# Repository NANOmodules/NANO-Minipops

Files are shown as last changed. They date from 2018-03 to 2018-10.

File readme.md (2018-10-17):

# NANO - Minipops

Arduino project based in Minipops design by Jan Ostman (DSP Synthesizers) 

The hardware consists in an Arduino Uno including it shield with 9 slide switches, 2 rotary potentiometers and 1 LED. 
Software in the CODE folder contains all the necessary to convert your Arduino Uno in a Minipops drum box.

**Click on the image to watch the presentation video!**

NANO-Minipops (https://www.youtube.com/watch?v=v7ahzl_3tDo&t=2s "NANO Minipops Presentation")

Link of the video: https://www.youtube.com/watch?v=v7ahzl_3tDo&t=2s
	
Jan project info: https://janostman.wordpress.com/the-o2-source-code/

This Github contains the information needed to build and flash an Arduino Minipops shield.

## Contents

Contents are divided in the following categories:

### BOM

```
Include the component list, with it’s values and additional information.
```

### CODE

```
Arduino sketch with the code needed to run the device.
```

### DESIGN FILES

```
KiCad files for the project, including schematic, PCB and the project itself.
```

### GERBERS

```
PCB fabrication files.
```

### SCHEMATIC

```
Electronic circuit design.
```

## Authors

* **Jorge Gutiérrez** - *NANO Modules* 

## License

This project is licensed under **CC BY-NC-SA 4.0** 

## About

**NANO Modules**

Instagram: @NANOmodules							

Facebook:  /NANOmodules

València - SPAIN 2018

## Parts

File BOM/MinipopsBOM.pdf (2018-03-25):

# NANO-Minipops BOM

Item | Qty | Reference(s) | Value | Link
1 | 1 C1 | 10uF | https://www.mouser.es/ProductDetail/Illinois-Capacitor-CDE/106RSS016M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
2 | 1 C2 | 100nF | https://www.mouser.es/ProductDetail/Vishay-Vitramon/VJ1206Y104KXXPW1BC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
3 | 1 D1 | LED | https://www.mouser.es/ProductDetail/VCC/VAOL-3LSBY2?qs=sGAEpiMZZMvHYEB9WUp7EneOMcS%2fsWISDhfbgpFft4c%3d
4 | 1 J1 | Jack | https://www.mouser.es/ProductDetail/CUI/SJ-3523-SMT-TR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
5 | 1 J2 | Conn_01x02 | Included in PIN HEADER
6 | 2 R1, R2 | 1k | https://www.mouser.es/ProductDetail/Yageo/RC1206FR-071KL?qs=sGAEpiMZZMvdGkrng054txdMlaQGj9fifQE6h7znBls%3d
7 | 2 RV1, RV2 | 10k | https://www.mouser.es/ProductDetail/ALPS/RK09K1130A5R?qs=sGAEpiMZZMtC25l1F4XBU3JeeCo7XMTlEtsTbzspqEg%3d
8 | 9 SW1, SW2, SW3, SW4, SW5, SW6, SW7, SW8, SW9 | _ | https://www.mouser.es/ProductDetail/CK/0S102011MS2QN1?qs=sGAEpiMZZMtHXLepoqNyVWY62gt1t1LcnC7P9o8LzYg%3d
9 | 1 XA1 | PCB Shield
10 | 4 PIN HEADER 10 | 2.54mm | https://www.mouser.es/ProductDetail/Amphenol-FCI/68000-410HLF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
11 | 1 ARD | Arduino_Uno | https://www.ebay.es/itm/UNO-R3-Rev3-ATmega328-16U2-Arduino-100-Compatible-cable-USB-ULTIMA-VERSION-B009/201530741428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

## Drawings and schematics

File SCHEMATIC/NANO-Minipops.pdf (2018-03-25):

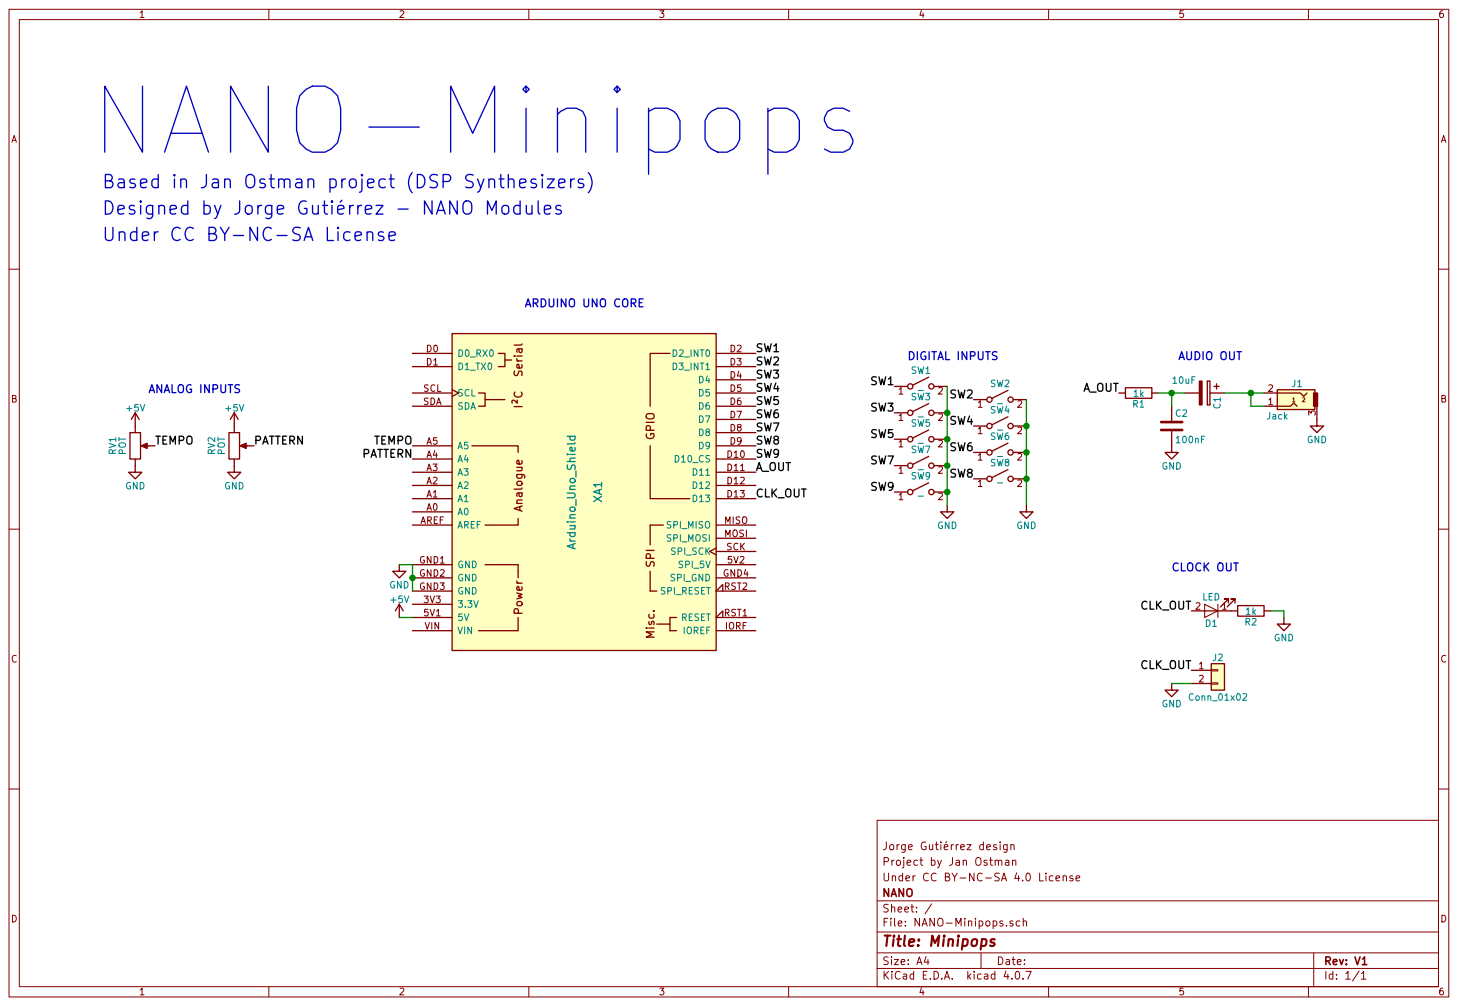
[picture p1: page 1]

Based in Jan Ostman project (DSP Synthesizers)
Designed by Jorge Gutiérrez - NANO Modules
Under CC BY-NC-SA License

Under CC BY-NC-SA 4.0 License Project by Jan Ostman

File: NANO-Minipops.sch Sheet: / NANO

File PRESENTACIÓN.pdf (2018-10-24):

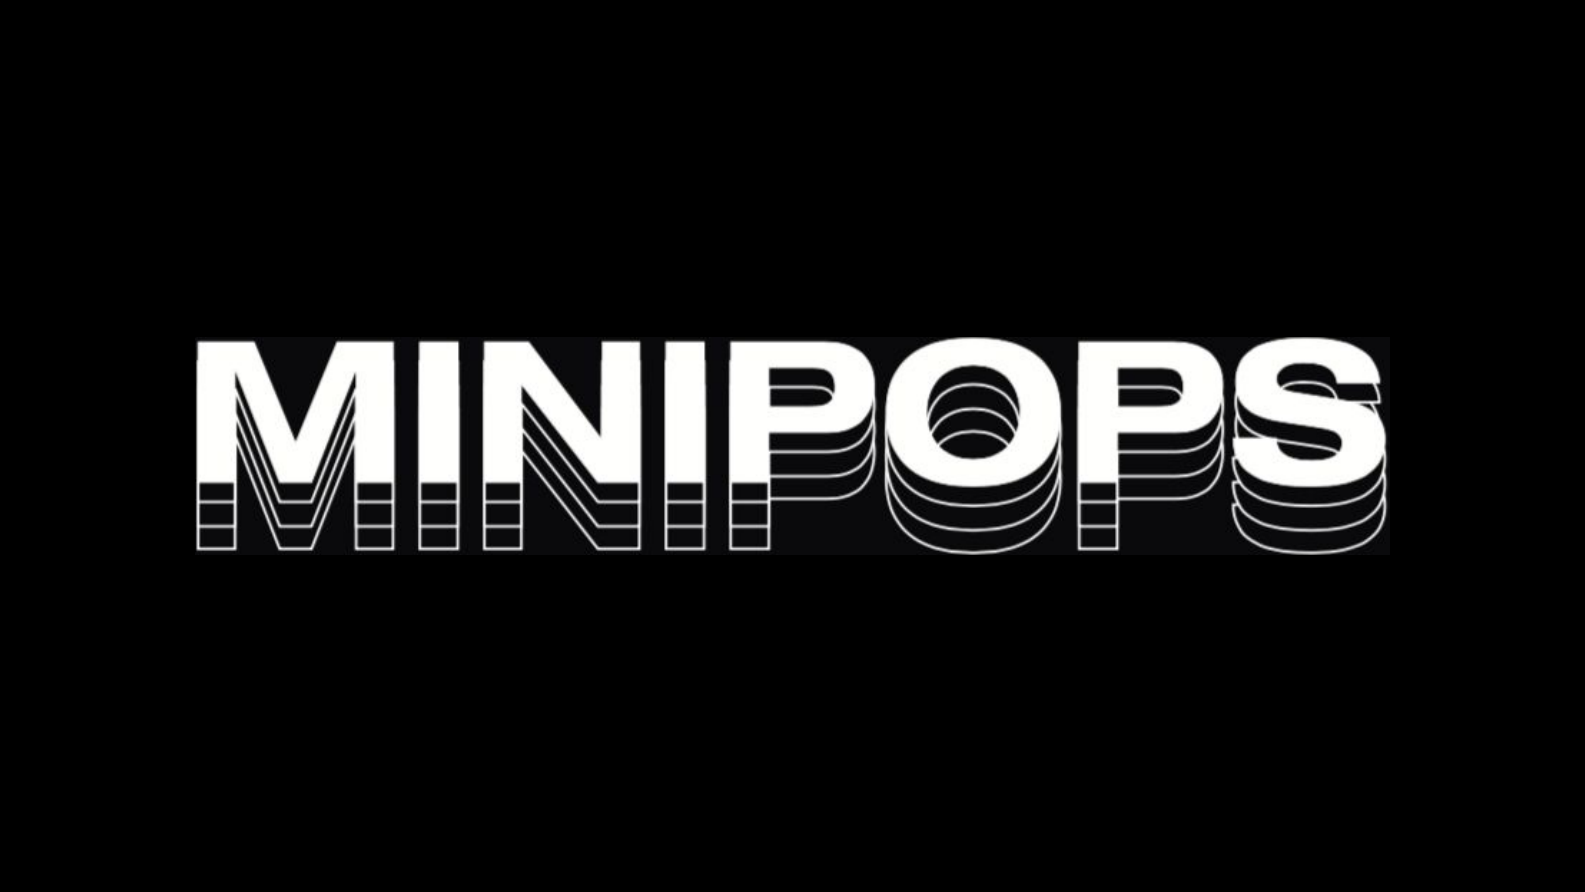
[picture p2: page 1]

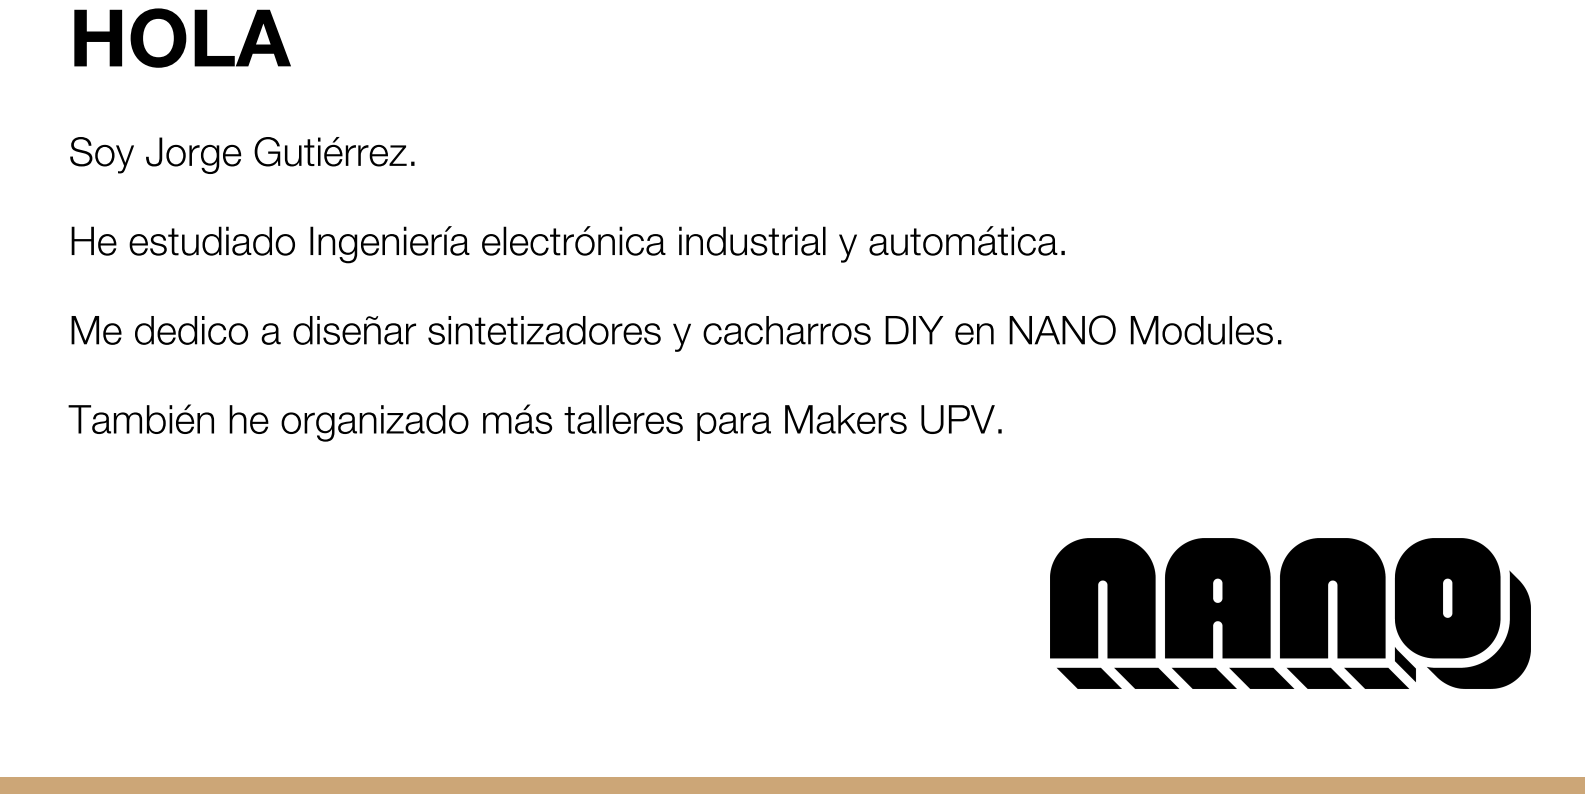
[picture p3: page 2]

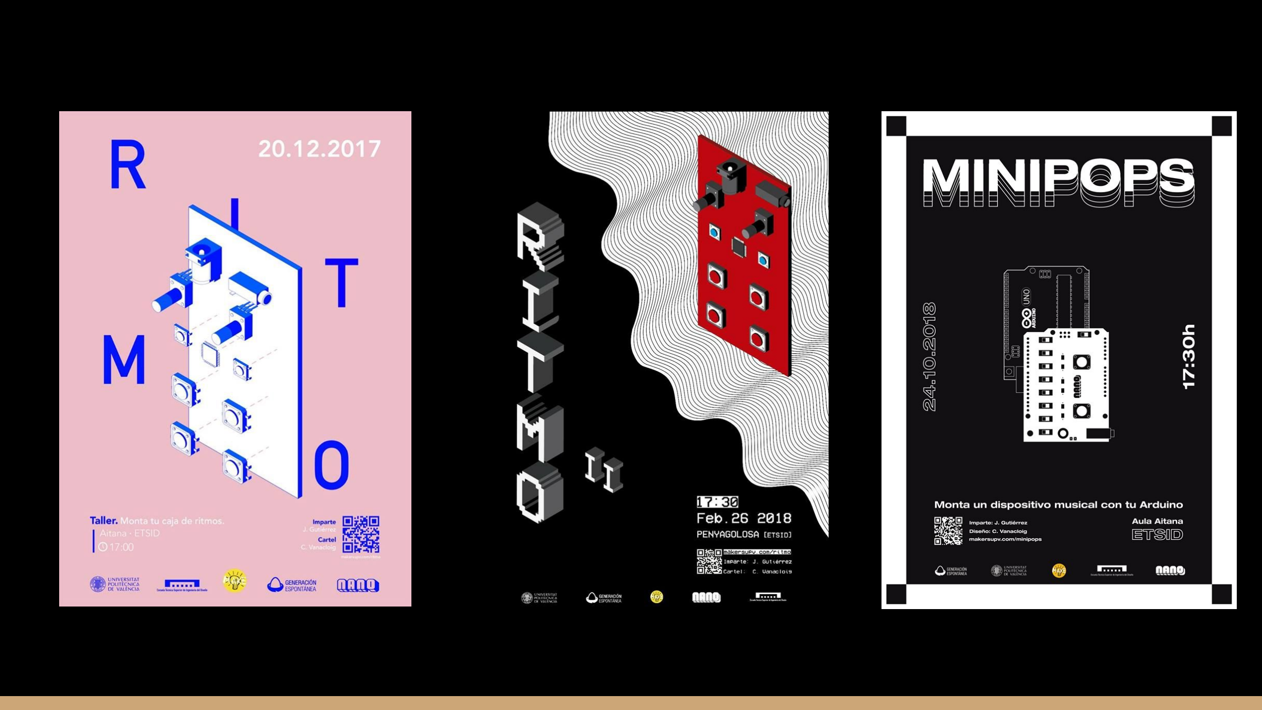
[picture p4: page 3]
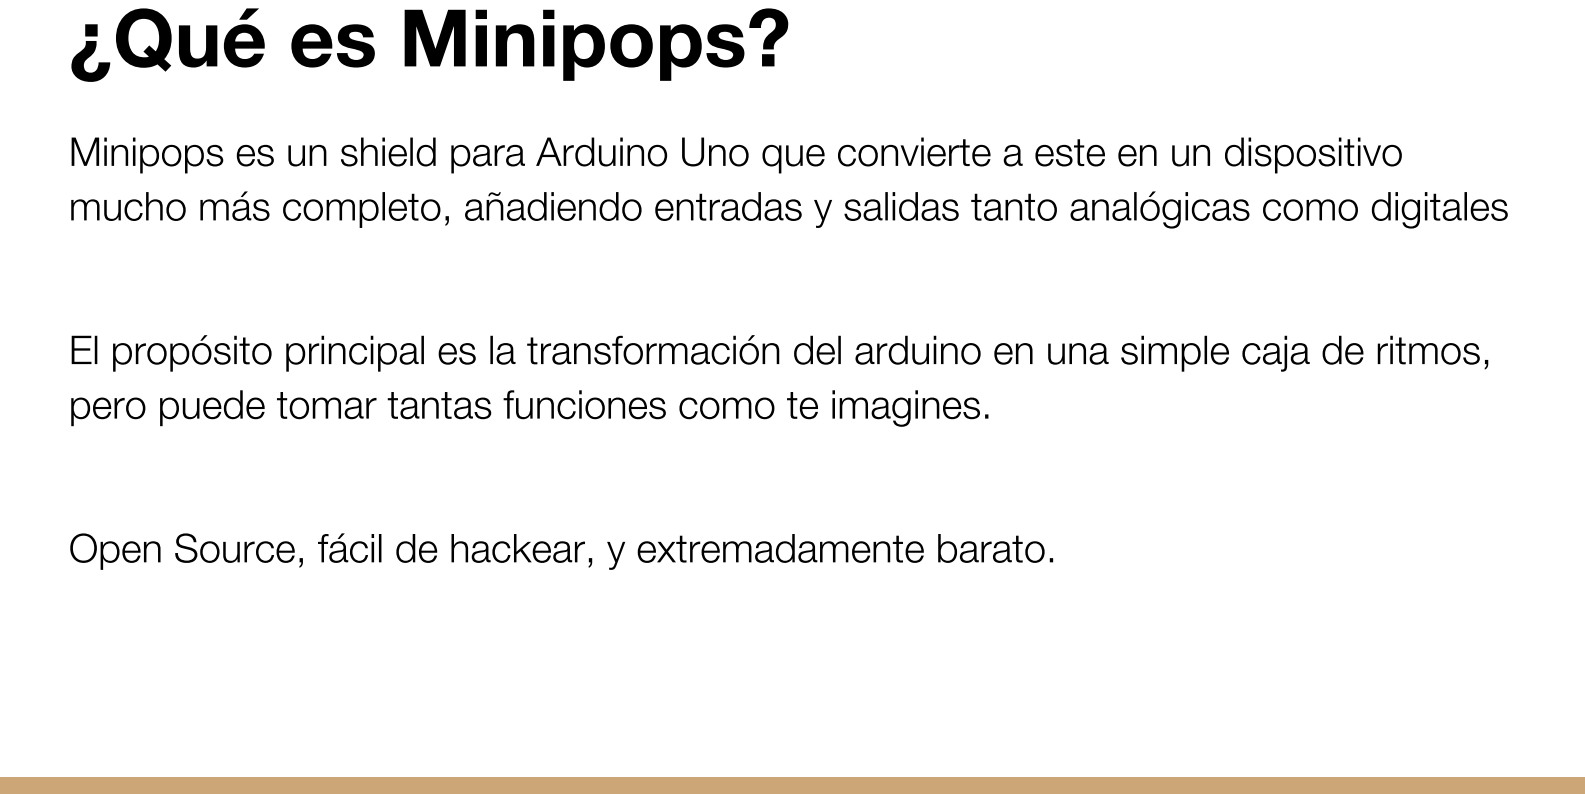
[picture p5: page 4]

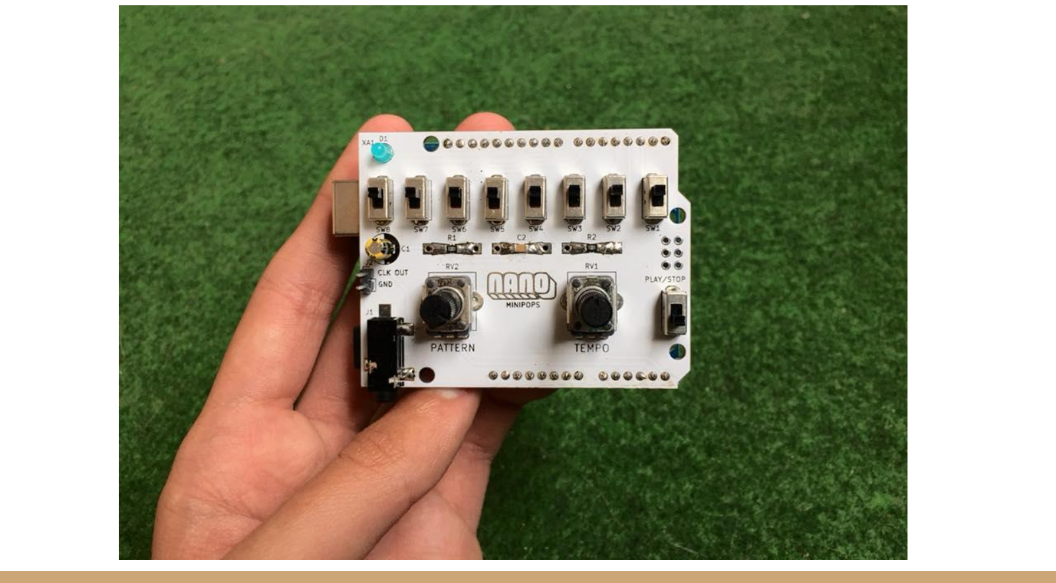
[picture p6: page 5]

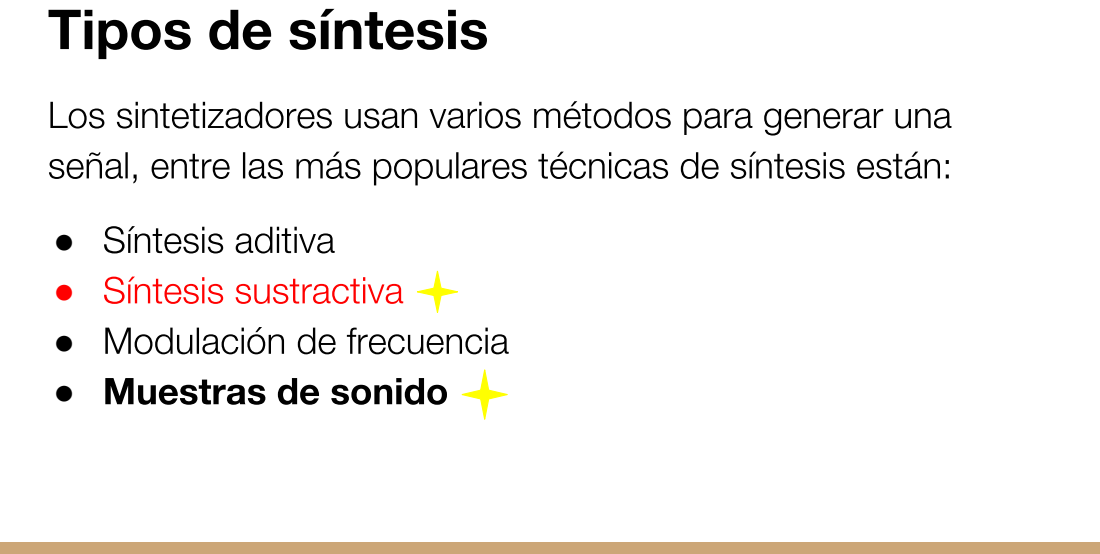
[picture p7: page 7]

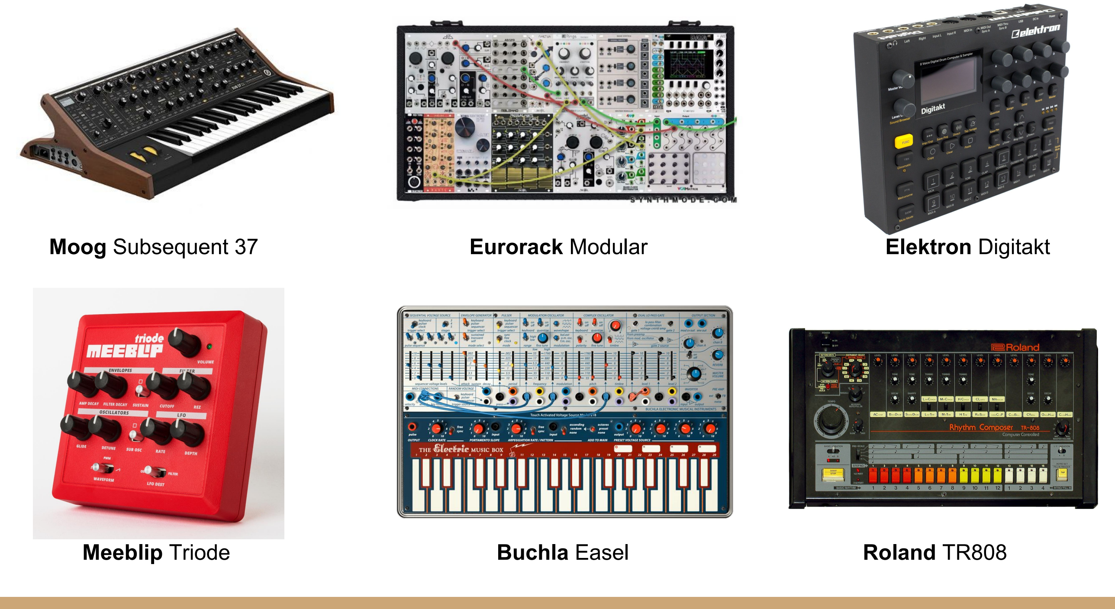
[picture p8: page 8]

Moog Subsequent 37 | Eurorack Modular | Elektron Digitakt
Meeblip Triode | Buchla Easel | Roland TR808

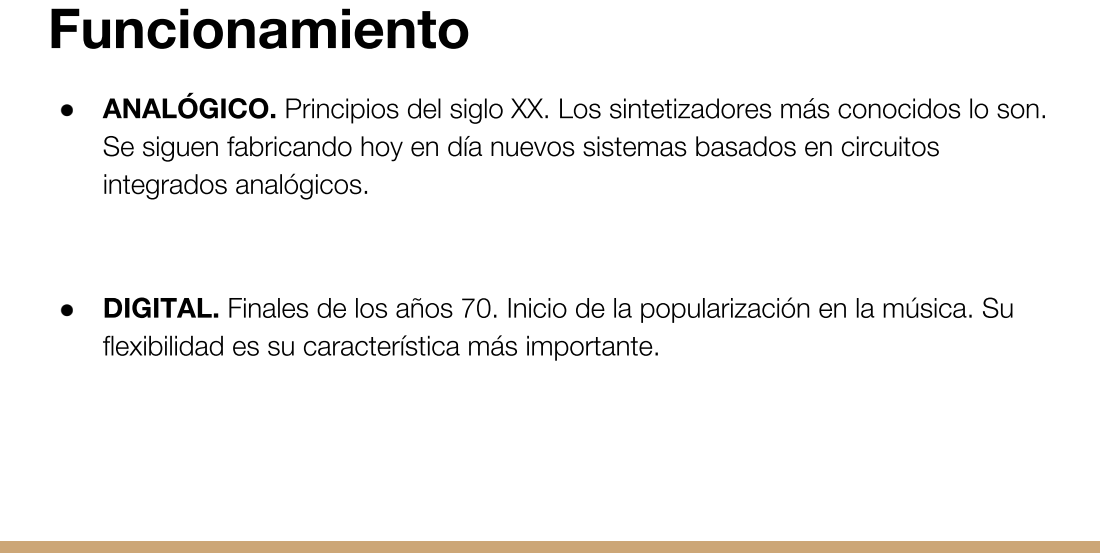
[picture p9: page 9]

# Roland Juno 60

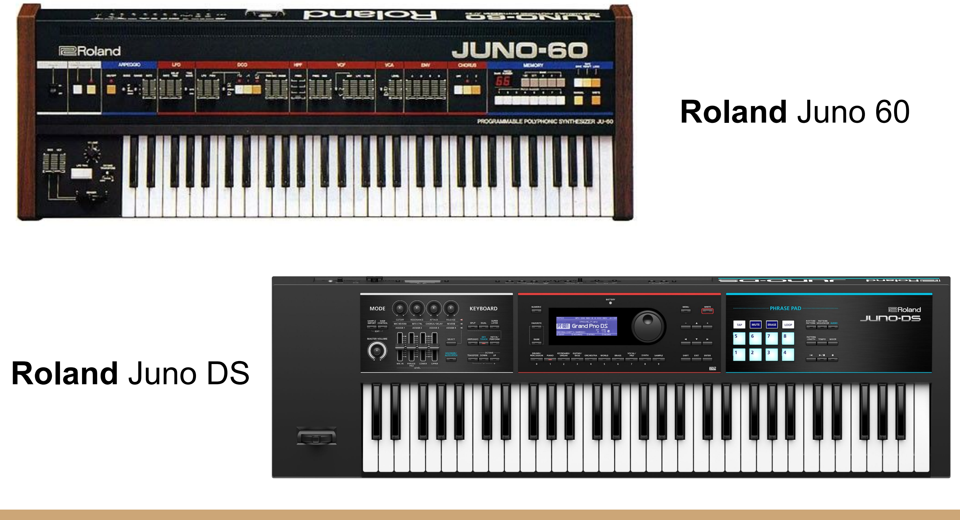
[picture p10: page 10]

# Roland Juno DS

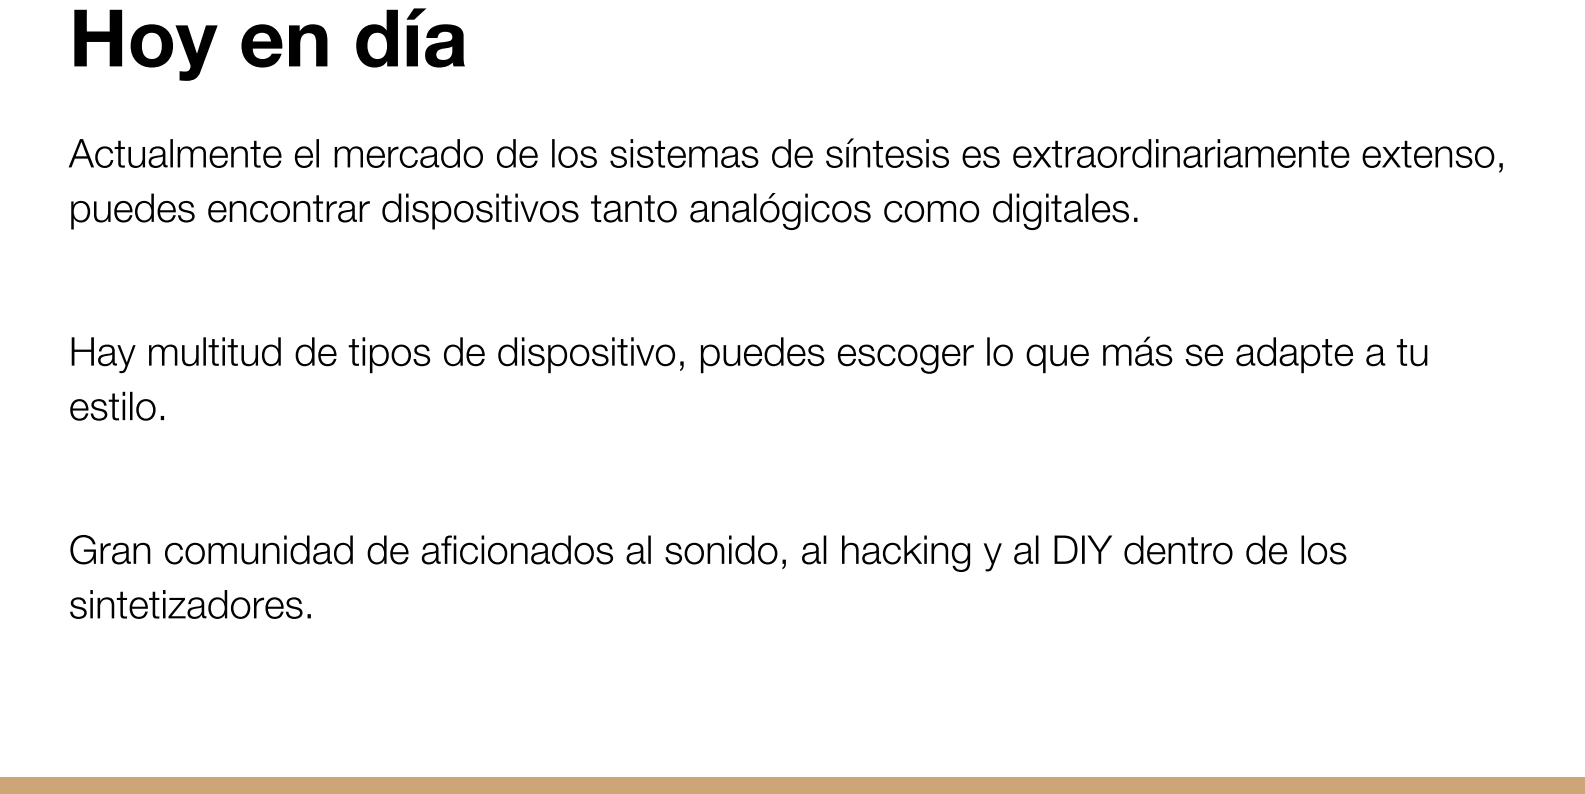
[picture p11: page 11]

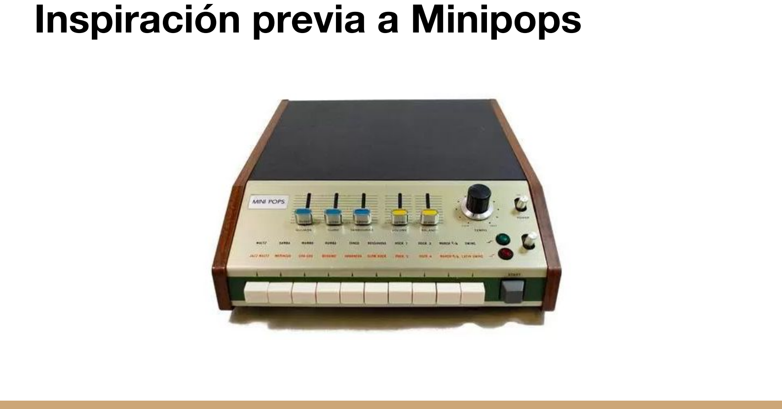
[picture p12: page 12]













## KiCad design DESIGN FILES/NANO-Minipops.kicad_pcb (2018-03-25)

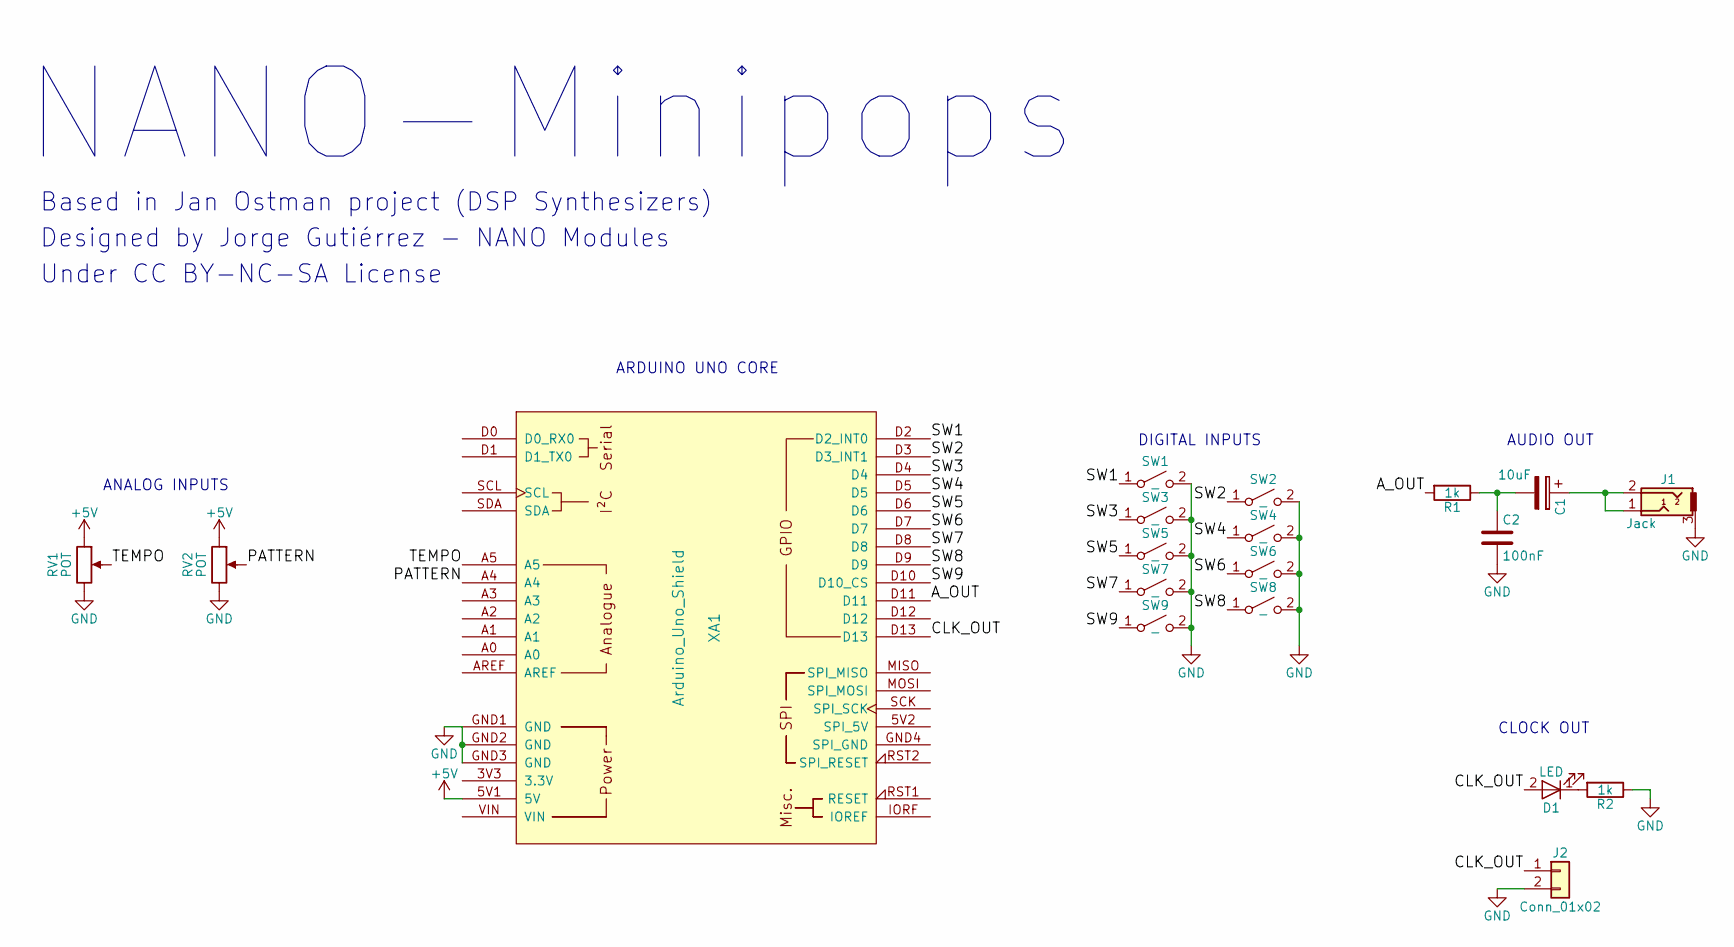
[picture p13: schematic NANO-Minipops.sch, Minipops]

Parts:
C1: 10uF; CP_Radial_D6.3mm_P2.50mm
C2: 100nF; C_Rect_L7.0mm_W2.0mm_P5.00mm
D1: LED; LED_D3.0mm
J1: Jack; Jack-CUI
J2: Conn_01x02; Pin_Header_Straight_1x02_Pitch2.54mm
R1, R2: 1k; Resistor_SMD+THTuniversal_0805to1206_RM10_HandSoldering
RV1, RV2: POT; Potentiometer_Alps_RK09K_Horizontal
SW1, SW2, SW3, SW4, SW5, SW6, SW7, SW8, SW9: _; SlideSwitch
XA1: Arduino_Uno_Shield

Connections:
+5V: RV1.1, RV2.1, XA1.5V1 (5V)
/A_OUT: R1.2, XA1.D11
/CLK_OUT: D1.2 (A), J2.1, XA1.D13
/PATTERN: RV2.2, XA1.A4
/SW1: SW1.1 (A), XA1.D2 (D2_INT0)
/SW2: SW2.1 (A), XA1.D3 (D3_INT1)
/SW3: SW3.1 (A), XA1.D4
/SW4: SW4.1 (A), XA1.D5
/SW5: SW5.1 (A), XA1.D6
/SW6: SW6.1 (A), XA1.D7
/SW7: SW7.1 (A), XA1.D8
/SW8: SW8.1 (A), XA1.D9
/SW9: SW9.1 (A), XA1.D10 (D10_CS); also elsewhere on the board
/TEMPO: RV1.2, XA1.A5
GND: C2.2, J1.3, J2.2, R2.1, RV1.3, RV2.3, SW1.2 (B), SW2.2 (B), SW3.2 (B), SW4.2 (B), SW5.2 (B), SW6.2 (B), SW7.2 (B), SW8.2 (B), SW9.2 (B), XA1.GND1 (GND), XA1.GND2 (GND), XA1.GND3 (GND); also elsewhere on the board
unnamed: C1.1, J1.1, J1.2
unnamed: C1.2, C2.1, R1.1
unnamed: D1.1 (K), R2.2

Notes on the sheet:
CLOCK OUT
AUDIO OUT
ARDUINO UNO CORE
ANALOG INPUTS
DIGITAL INPUTS
NANO-Minipops
Based in Jan Ostman project (DSP Synthesizers)
Designed by Jorge Gutiérrez - NANO Modules
Under CC BY-NC-SA License

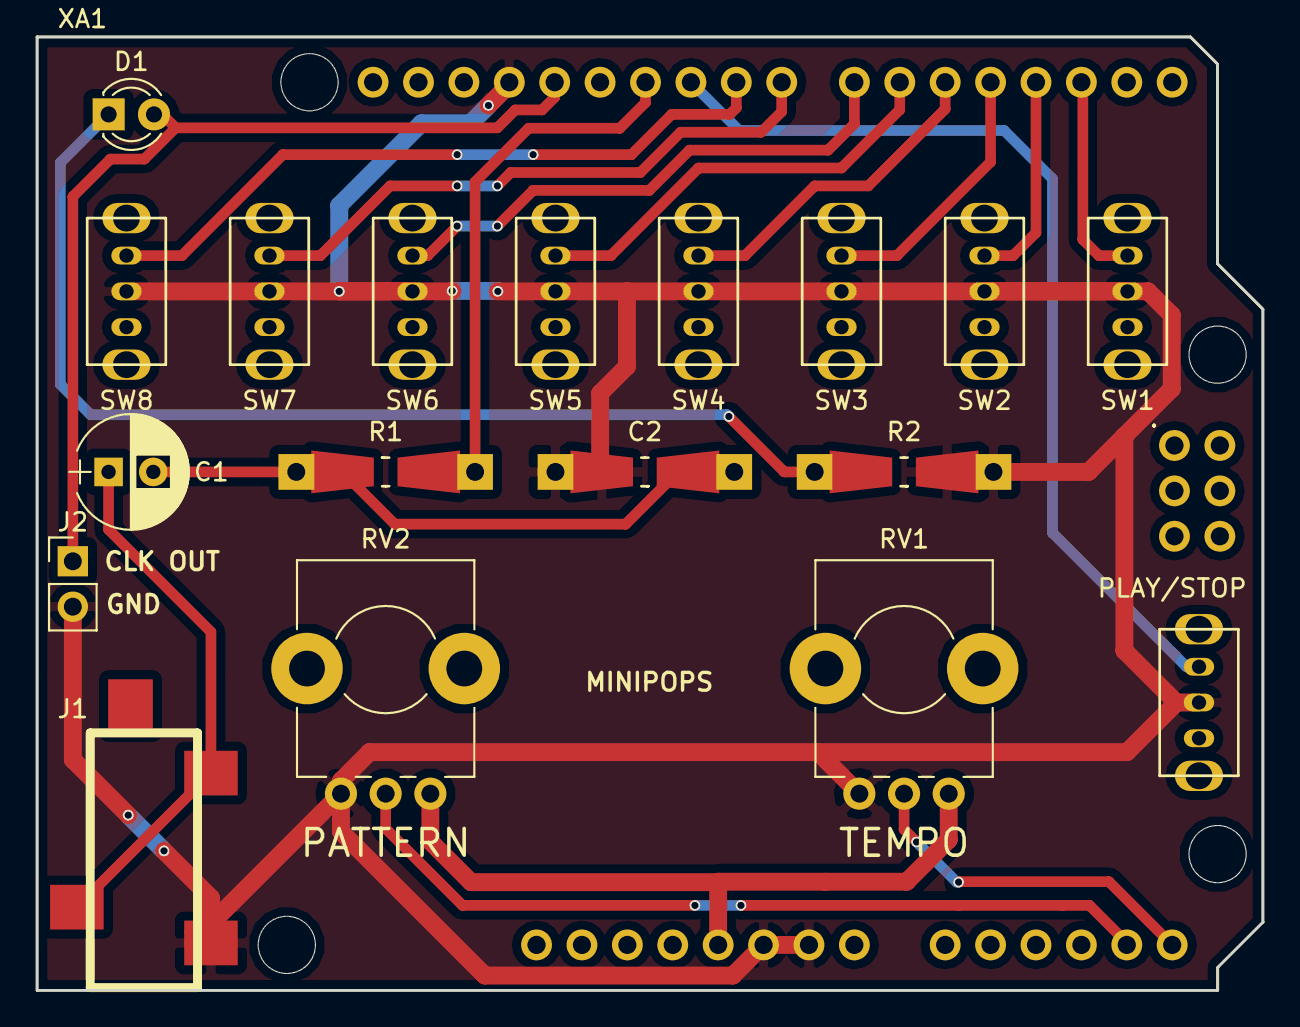
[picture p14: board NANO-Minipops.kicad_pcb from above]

Board: 2 copper layers, 68.6 x 53.3 mm, 19 parts (0 on the bottom side), 18 nets.

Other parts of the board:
PLAY/STOP: _; SlideSwitch

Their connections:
/SW9: PLAY/STOP.1; also elsewhere on the board
GND: PLAY/STOP.2; also elsewhere on the board

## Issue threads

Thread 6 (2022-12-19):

Tempo

jojo-monk, 2022-12-19:
When I turn the tempo potentiometer to the left, the tempo accelerates, how to reverse this without wiring the potentiometer upside down ?

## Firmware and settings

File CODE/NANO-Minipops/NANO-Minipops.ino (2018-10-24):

// All in the spirit of open-source and open-hardware
//
// Minipops rhythm box
// Code by Jan Ostman
// 
// Design by Jorge Gutiérrez
// 
// 2018 Spain
//
// Free for non commercial use
//
// NANO Modules
//

#include "includes.h"

#include <avr/io.h>
#include <avr/pgmspace.h>
#include <avr/interrupt.h>

#define DEBUG   0

#ifndef cbi
#define cbi(sfr, bit) (_SFR_BYTE(sfr) &= ~_BV(bit))
#endif
#ifndef sbi
#define sbi(sfr, bit) (_SFR_BYTE(sfr) |= _BV(bit))
#endif 

// Standard Arduino Pins
#define digitalPinToPortReg(P) \
(((P) >= 0 && (P) <= 7) ? &PORTD : (((P) >= 8 && (P) <= 13) ? &PORTB : &PORTC))
#define digitalPinToDDRReg(P) \
(((P) >= 0 && (P) <= 7) ? &DDRD : (((P) >= 8 && (P) <= 13) ? &DDRB : &DDRC))
#define digitalPinToPINReg(P) \
(((P) >= 0 && (P) <= 7) ? &PIND : (((P) >= 8 && (P) <= 13) ? &PINB : &PINC))
#define digitalPinToBit(P) \
(((P) >= 0 && (P) <= 7) ? (P) : (((P) >= 8 && (P) <= 13) ? (P) - 8 : (P) - 14))

#define digitalReadFast(P) bitRead(*digitalPinToPINReg(P), digitalPinToBit(P))
                  
#define digitalWriteFast(P, V) bitWrite(*digitalPinToPortReg(P), digitalPinToBit(P), (V))

unsigned long millis(void);

const unsigned char PS_128 = (1 << ADPS2) | (1 << ADPS1) | (1 << ADPS0);

ISR(TIMER1_COMPA_vect) {
  
    //-------------------  Ringbuffer handler -------------------------
    
    if (RingCount) {                            //If entry in FIFO..
      OCR2A = Ringbuffer[(RingRead++)];          //Output LSB of 16-bit DAC
      RingCount--;
    }
    
    //-----------------------------------------------------------------

}



void setup() {
  
    OSCCAL=0xFF;

    if (DEBUG){   
    // initialize serial:
    Serial.begin(9600);}
    
    //Drum mute inputs
    pinMode(2,INPUT_PULLUP);
    pinMode(3,INPUT_PULLUP);
    pinMode(4,INPUT_PULLUP);
    pinMode(5,INPUT_PULLUP);
    pinMode(6,INPUT_PULLUP);
    pinMode(7,INPUT_PULLUP);
    pinMode(8,INPUT_PULLUP);
    pinMode(9,INPUT_PULLUP);

    pinMode(10,INPUT_PULLUP); //RUN - Stop input
    pinMode(12,OUTPUT);       //Reset output
    pinMode(13,OUTPUT);       //Clock output

    pinMode(14,OUTPUT);       //SEQ cnt output
    pinMode(15,OUTPUT); 
    pinMode(16,OUTPUT); 
    pinMode(17,OUTPUT); 
    
    //8-bit PWM DAC pin
    pinMode(11,OUTPUT);

    // Set up Timer 1 to send a sample every interrupt.
    cli();
    // Set CTC mode
    // Have to set OCR1A *after*, otherwise it gets reset to 0!
    TCCR1B = (TCCR1B & ~_BV(WGM13)) | _BV(WGM12);
    TCCR1A = TCCR1A & ~(_BV(WGM11) | _BV(WGM10));    
    // No prescaler
    TCCR1B = (TCCR1B & ~(_BV(CS12) | _BV(CS11))) | _BV(CS10);
    // Set the compare register (OCR1A).
    // OCR1A is a 16-bit register, so we have to do this with
    // interrupts disabled to be safe.
    //OCR1A = F_CPU / SAMPLE_RATE; 
    // Enable interrupt when TCNT1 == OCR1A
    TIMSK1 |= _BV(OCIE1A);   
    sei();
    OCR1A = 800; //40KHz Samplefreq

// Set up Timer 2 to do pulse width modulation on D11

    // Use internal clock (datasheet p.160)
    ASSR &= ~(_BV(EXCLK) | _BV(AS2));

    // Set fast PWM mode  (p.157)
    TCCR2A |= _BV(WGM21) | _BV(WGM20);
    TCCR2B &= ~_BV(WGM22);

    // Do non-inverting PWM on pin OC2A (p.155)
    // On the Arduino this is pin 11.
    TCCR2A = (TCCR2A | _BV(COM2A1)) & ~_BV(COM2A0);
    TCCR2A &= ~(_BV(COM2B1) | _BV(COM2B0));
    // No prescaler (p.158)
    TCCR2B = (TCCR2B & ~(_BV(CS12) | _BV(CS11))) | _BV(CS10);

    // Set initial pulse width to the first sample.
    OCR2A = 128;

    //set timer0 interrupt at 61Hz
    TCCR0A = 0;// set entire TCCR0A register to 0
    TCCR0B = 0;// same for TCCR0B
    TCNT0  = 0;//initialize counter value to 0
    // set compare match register for 62hz increments
    OCR0A = 255;// = 61Hz
    // turn on CTC mode
    TCCR0A |= (1 << WGM01);
    // Set CS01 and CS00 bits for prescaler 1024
    TCCR0B |= (1 << CS02) | (0 << CS01) | (1 << CS00);  //1024 prescaler 

    TIMSK0=0;


    // set up the ADC
    SFREQ=analogRead(0);
    ADCSRA &= ~PS_128;  // remove bits set by Arduino library
    // Choose prescaler PS_128.
    ADCSRA |= PS_128;
    ADMUX = 64;
    sbi(ADCSRA, ADSC);
         
}

void loop() {  

  uint16_t samplecntBD,samplecntBG2,samplecntCL,samplecntCW,samplecntCY,samplecntGU,samplecntMA,samplecntQU;

  samplecntBD=0;
  samplecntBG2=0;
  samplecntCL=0;
  samplecntCW=0;
  samplecntCY=0;
  samplecntGU=0;
  samplecntMA=0;
  samplecntQU=0;

  uint16_t samplepntBD,samplepntBG2,samplepntCL,samplepntCW,samplepntCY,samplepntGU,samplepntMA,samplepntQU;
  
  int16_t total;

  uint8_t stepcnt=0;
  uint16_t tempo=3500;
  uint16_t tempocnt=1;
  uint8_t MUX=4;

  uint8_t patselect=13;
  uint8_t patlength=pgm_read_byte_near(patlen + patselect);
  
  while(1) {

    //------ Add current sample word to ringbuffer FIFO --------------------  
        
    if (RingCount<255) {  //if space in ringbuffer
      total=0;
      if (samplecntBD) {
        total+=(pgm_read_byte_near(BD + samplepntBD++)-128);
        samplecntBD--;
      }
      if (samplecntBG2) {
        total+=(pgm_read_byte_near(BG2 + samplepntBG2++)-128);
        samplecntBG2--;
      }
      if (samplecntCL) {
        total+=(pgm_read_byte_near(CL + samplepntCL++)-128);
        samplecntCL--;
      }
      if (samplecntCW) {
        total+=(pgm_read_byte_near(CW + samplepntCW++)-128);
        samplecntCW--;
      }
      if (samplecntCY) {
        total+=(pgm_read_byte_near(CY + samplepntCY++)-128);
        samplecntCY--;
      }
      if (samplecntGU) {
        total+=(pgm_read_byte_near(GU + samplepntGU++)-128);
        samplecntGU--;
      }
       if (samplecntMA) {
        total+=(pgm_read_byte_near(MA + samplepntMA++)-128);
        samplecntMA--;
      }
      if (samplecntQU) {
        total+=(pgm_read_byte_near(QU + samplepntQU++)-128);
        samplecntQU--;
      }
      if (total<-127) total=-127;
      if (total>127) total=127;                           
      cli();
      Ringbuffer[RingWrite]=total+128;
      RingWrite++;
      RingCount++;
      sei();
 

//----------------------------------------------------------------------------

//--------- sequencer block ----------------------------------------------
if (digitalReadFast(10)) {
  if (!(tempocnt--)) {
    tempocnt=tempo;
    
    digitalWriteFast(13,HIGH); //Clock out Hi
    
    uint8_t trig=pgm_read_byte_near(pattern + (patselect<<4) + stepcnt++);
    PORTC=stepcnt;
    uint8_t mask=(PIND>>2)|((PINB&3)<<6);
    trig&=mask;
    if (stepcnt>patlength) stepcnt=0;
    //if (stepcnt==0) digitalWriteFast(12,HIGH);//Reset out DISABLED
    //if (stepcnt!=0) digitalWriteFast(12,LOW); //Reset out DISABLED
    if (trig & 1) {
      samplepntQU=0;
      samplecntQU=7712;
    }
    if (trig & 2) {
      samplepntCY=0;
      samplecntCY=9434;
    }
    if (trig & 4) {
      samplepntMA=0;
      samplecntMA=568;
    }
    if (trig & 8) {
      samplepntCW=0;
      samplecntCW=830;
    }
    if (trig & 16) {
      samplepntCL=0;
      samplecntCL=752;
    }
    if (trig & 32) {
      samplepntBD=0;
      samplecntBD=1076;
    }
    if (trig & 64) {
      samplepntBG2=0;
      samplecntBG2=1136;
    }
    if (trig & 128) {
      samplepntGU=0;
      samplecntGU=2816;
    }
  }
  
    if (micros() - previousMicros >= 525) {
      
    digitalWriteFast(13,LOW); //Disable toggle
    activeRead = 0; 
    previousMicros = micros();
    } else {
    }
    
/*
  if(activeRead >= 250 && (micros() - previousMicros) >= 500) {
    digitalWriteFast(13,LOW); //Disable toggle
    activeRead = 0; 
    previousMicros = micros();
  } else {
    activeRead++;
  } */
    if(DEBUG){
    Serial.println(micros()-previousMicros); 
    }
  }  
}
    
if (!(digitalReadFast(10))) {
 digitalWriteFast(13,LOW);  //Clock out LOW
 //digitalWriteFast(12,LOW); //Reset out DISABLED
  PORTC=0;
  stepcnt=0;
  tempocnt=1;
}
//------------------------------------------------------------------------



//--------------- ADC block -------------------------------------
    if (!(ADCSRA & 64)) {

      uint16_t value=((ADCL+(ADCH<<8))>>3)+1;
      if (MUX==5) tempo=(value<<4)+1250;  //17633-1250
      if (MUX==4) patselect=(value-1)>>3;
      if (MUX==4) patlength=pgm_read_byte_near(patlen + patselect);
      
      MUX++;
      if (MUX==8) MUX=4;
      ADMUX = 64 | MUX; //Select MUX
      sbi(ADCSRA, ADSC); //start next conversation
    };
//---------------------------------------------------------------
    
  }
}

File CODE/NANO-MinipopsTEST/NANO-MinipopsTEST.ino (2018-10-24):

// All in the spirit of open-source and open-hardware
// 
// Design by Jorge Gutiérrez
// 
// 2018 Spain
//
// Free for non commercial use
//
// NANO Modules
//

int state;

void setup() {

  Serial.begin(9600);

  //JUMPERS
  pinMode(2,INPUT_PULLUP);
  pinMode(3,INPUT_PULLUP);
  pinMode(4,INPUT_PULLUP);
  pinMode(5,INPUT_PULLUP);
  pinMode(6,INPUT_PULLUP);
  pinMode(7,INPUT_PULLUP);
  pinMode(8,INPUT_PULLUP);
  pinMode(9,INPUT_PULLUP);

  //SWITCH
  pinMode(10,INPUT_PULLUP);

  //ANALOG INPUTS
  pinMode(A4,INPUT);
  pinMode(A5,INPUT);

  //LED
  pinMode(13,OUTPUT);
}

void blinkLED(){
  digitalWrite(13, HIGH);   // turn the LED on (HIGH is the voltage level)
  delay(500);                       // wait for a second
  digitalWrite(13, LOW);    // turn the LED off by making the voltage LOW
  delay(500);  
}

void toggleTone(){
  if (state){
  tone(11,50);
  } else { 
  tone(11,100);}
  state = !state;
}

void loop() {
  // put your main code here, to run repeatedly:
  if (digitalRead(10) == 1){
    Serial.println("System ON");
    Serial.println("");
    
    blinkLED();
    
    toggleTone();
    
    Serial.println("DIGITAL READINGS");
    Serial.print("SW1: ");
    Serial.print(digitalRead(9));
    Serial.print(" SW2: ");
    Serial.print(digitalRead(8));
    Serial.print(" SW3: ");
    Serial.print(digitalRead(7));
    Serial.print(" SW4: ");
    Serial.print(digitalRead(6));
    Serial.print(" SW5: ");
    Serial.print(digitalRead(5));
    Serial.print(" SW6: ");
    Serial.print(digitalRead(4));
    Serial.print(" SW7: ");
    Serial.print(digitalRead(3));
    Serial.print(" SW8: ");
    Serial.println(digitalRead(2));

    Serial.println("ANALOG READINGS");
    Serial.print("A4: ");
    Serial.print(analogRead(A4));
    Serial.print(" A5: ");
    Serial.println(analogRead(A5));
    Serial.println("");

    tone(11, 110);
  }
  else {  Serial.println("System OFF");
  delay(1000);
  }

}

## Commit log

2018-03-25 Adding things
    [NANO-Minipops-B.Cu.gbr, NANO-Minipops-B.Mask.gbr, NANO-Minipops-B.SilkS.gbr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]
2018-03-25 Improved PCB
    [NANO-Minipops-B.Cu.gbr, NANO-Minipops-B.Mask.gbr, NANO-Minipops-B.SilkS.gbr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]
2018-03-25 Added BOM
    [NANO-Minipops.kicad_pcb]
